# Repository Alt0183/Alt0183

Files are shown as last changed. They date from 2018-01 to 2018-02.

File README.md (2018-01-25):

Alt0183 est le caractère du point milieu, dont l'usage participe à l'égalité des représentations entre les femmes et les hommes dans l'écriture. C'est aussi une extension de clavier open source pour cliquer sans modération et susciter le débat !

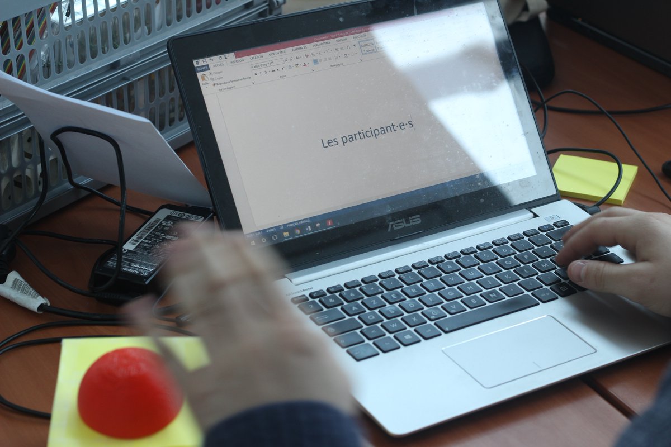
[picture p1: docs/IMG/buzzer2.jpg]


## Comment ça marche ?

- Fabriquez votre boîtier [en suivant les instructions ici](docs/INSTRUCTIONS)
- Connectez-le à votre ordinateur par USB, rien à installer
- Appuyez l'égalité dans le langage !

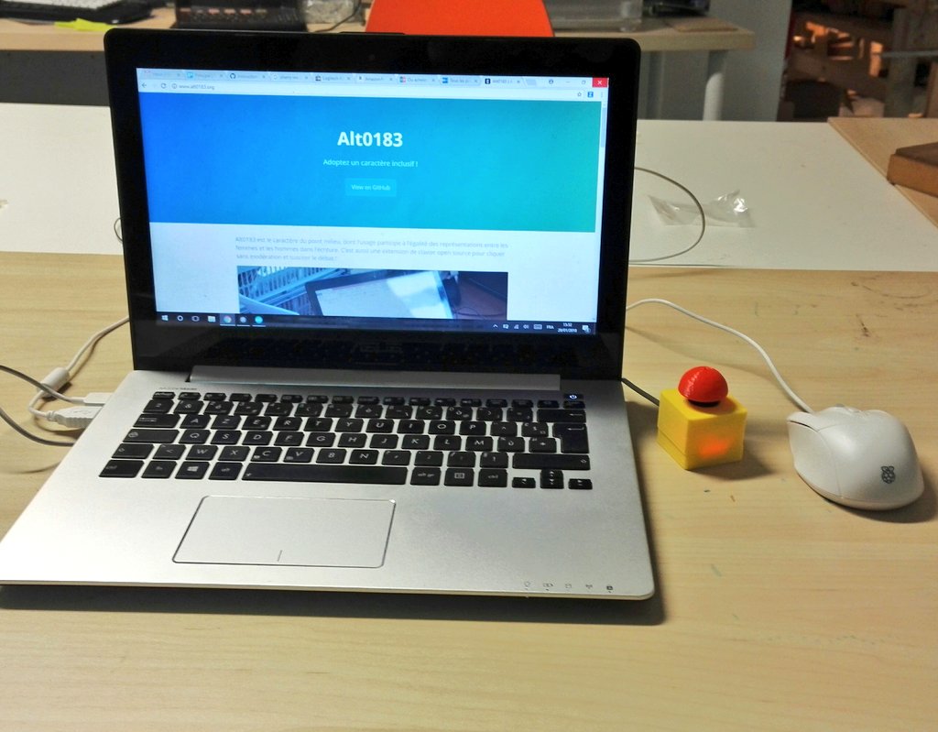
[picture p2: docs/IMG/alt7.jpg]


- Clic simple = "·"
- Double clic = "·es"

## Participez à un atelier pour fabriquer votre boitier Alt0183

Vous pensez ne pas savoir comment fabriquer un bouton Alt0183? Nous allons vous prouver le contraire! =)

Prochain atelier le 17 février à 14h au SimplonLab --> [INSCRIPTIONS](https://fabmanager.simplon.co/#!/events/31) 

## Ressources sur l'écriture inclusive

> « Le genre masculin ne sera plus regardé, même dans la grammaire, comme le genre le plus noble, attendu que tous les genres, tous les sexes et tous les êtres doivent être et sont également nobles. »  

*Requête des dames à l'Assemblée nationale, article 3 du Projet de décret adressé à la Législative, 1792.*

Voici une sélection de ressources pour alimenter vos discussions sur l'écriture inclusive et passer à l'action :

- [Le Guide pratique pour une communication publique sans stéréotype de sexe](http://www.haut-conseil-egalite.gouv.fr/stereotypes-et-roles-sociaux/zoom-sur/article/pour-une-communication-sans)

- [Le manuel d'écriture inclusive de l'agence Mots-Clés](http://www.ecriture-inclusive.fr/)

- [Épinglons-les : initiative militante pour l'emploi du langage inclusif en entreprise](https://epinglons-les.hotglue.me/?start.auto-20180114143251/)

- [Enrichissez votre vocabulaire en découvrant Égalexique, le lexique égalitaire](http://www.egalexique.com/)

- [Un programme collaboratif d'une semaine sur le thème du langage inclusif](http://semaineinclusive-hackecritureinclusive18.strikingly.com/)

## Suivre les avancées du projet

N'hésitez pas à nous laisser votre adresse mail pour être tenu·e informé·e des avancées du projet :

<script src="assets/js/jquery.min.js"></script>
<script type="text/javascript">var submitted=false;</script>
<script type="text/javascript">
$('#gform').on('submit', function(e) {
  $('#gform *').fadeOut(2000);
  $('#gform').prepend('Your submission has been processed...');
  });
</script>

<div style="text-align:center"><form name="gform" id="gform" enctype="text/plain" action="https://docs.google.com/forms/d/e/1FAIpQLSesBYaVCQM-NDpRlMn8QnpjHFccGZ0p6LW1I69tBJElzHB0rA/formResponse?" target="hidden_iframe" onsubmit="submitted=true;">
  Adresse mail:
  <input type="text" name="entry.119910746" id="entry.119910746">
  <!--Commentaire : <br>
  <input type="text" name="entry.383631987" id="entry.383631987"> -->
  <input type="submit" value="Envoyer">
</form>

<iframe name="hidden_iframe" id="hidden_iframe" style="display:none;" onload="if(submitted) {}"></iframe> <br>
</div>

Pour toute autre demande, n'hésitez pas à nous contacter par mail ou via les réseaux sociaux, nous ferons notre possible pour vous répondre le plus rapidement possible :

[Contact](mailto:contact.alt0183@gmail.com) | [Twitter](https://twitter.com/Alt0183_) | [Instagram](https://www.instagram.com/Alt0183)

# Contribuer

Vous souhaitez participer au projet? Organiser un atelier? Fabriquer, voire commercialiser, des boutons Alt0183?

Les différentes manières de s'impliquer dans le projet sont décrites sur [cette page](docs/contribuer).

---

Ce projet a été réalisé lors du Hackathon écriture inclusive 13/14 janvier 2018 par [Guillaume Marion](https://github.com/guillaumemarion) et est partagé sous licence GNU General Public License v3.0

Merci aux personnes ayant organisé ce hackathon, aux participant·es ainsi qu'aux sponsors!

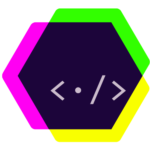
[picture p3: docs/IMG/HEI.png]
<div style="text-align:center"></div>

---

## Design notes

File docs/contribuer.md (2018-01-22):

# Contribuer au projet
Plusieurs moyens de contribuer au projet existent selon vos envies et vos compétences.

## Proposer des idées d'améliorations

Si vous avez une idée ou une proposition d'amélioration mais que vous ne savez pas comment la réaliser, il suffit d'aller dans l'onglet "issues" ci dessus et de la proposer. Cela permettra à celles et ceux qui savent coder/fabriquer d'essayer de les intégrer.

## Modifier le code, corriger un bug, proposer un boitier à imprimer en 3D, ajouter une version, etc...

Pour celles et ceux qui savent utiliser GitHub, vous pouvez directement proposer des CAO de boitier à imprimer en 3D, des améliorations de codes, des exemples de boitiers réalisés avec d'autres cartes Arduino, etc...
Pensez juste à ajouter une descriptions avant de commiter pour faciliter l'acceptation de vos modifications par les autres contributeur·rices

N'hésitez pas à aller faire un tour sur [la page "project"](https://github.com/guillaumemarion/Alt0183/projects/2) pour savoir quels sont les bugs ou les propositions d'améliorations à traiter et pour voir ce que font les autres.

## Organiser un atelier fabrication Alt0183

Si vous souhaitez organiser un atelier de fabrication d'Alt0183, n'hésitez pas! Pensez à nous prévenir pour que l'on diffuse l'invitation à votre atelier si vous le souhaitez

## Proposer des ressources à publier sur la page d'accueil

## Partagez vos photos

La meilleure reconnaissance que nous pouvons avoir de votre part est de savoir que vous utilisez Alt0183. N'hésitez donc pas à nous envoyer vos photos de vos versions de Alt0183 en situation par mail ou sur Instagram avec le hashtag #Alt0183!

## Envoyez nous un mail

Pour toute question, renseignement, problème ou autre, n'hésitez pas à nous [envoyer un mail](contact.alt0183@gmail.com)

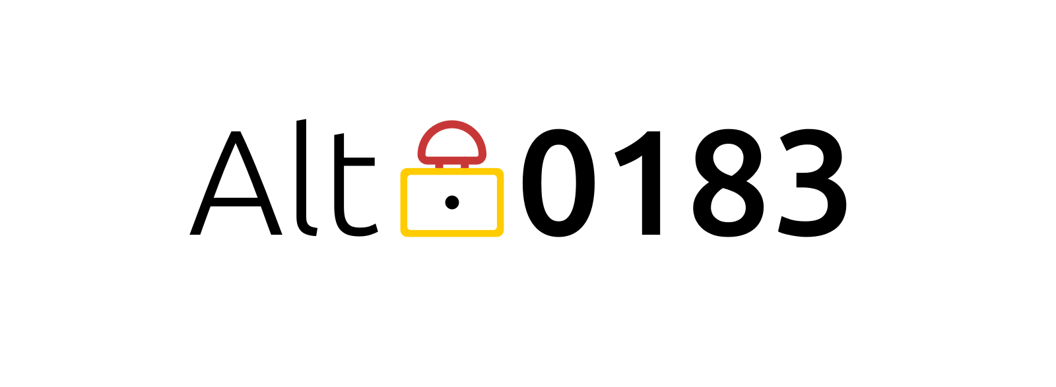
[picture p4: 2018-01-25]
docs/IMG/cover.png

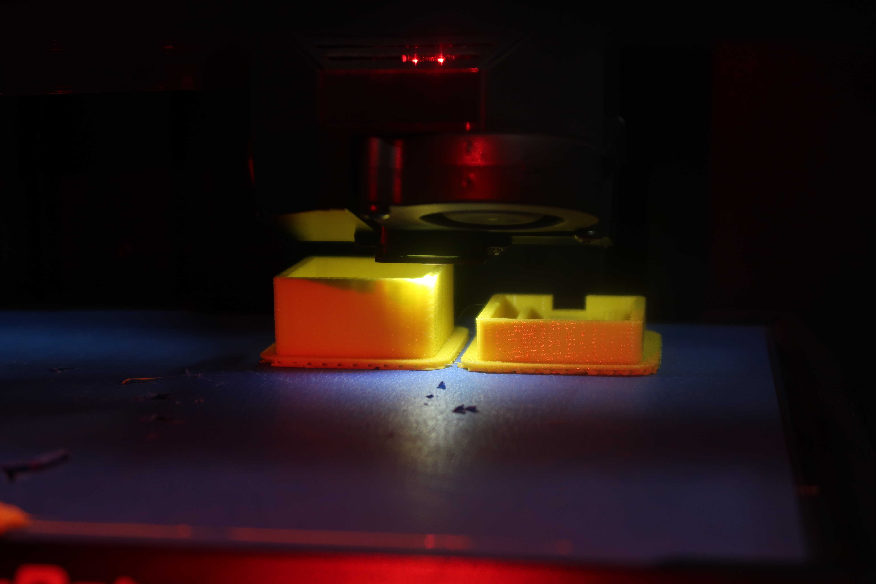
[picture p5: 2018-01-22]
docs/IMG/alt-1.jpg

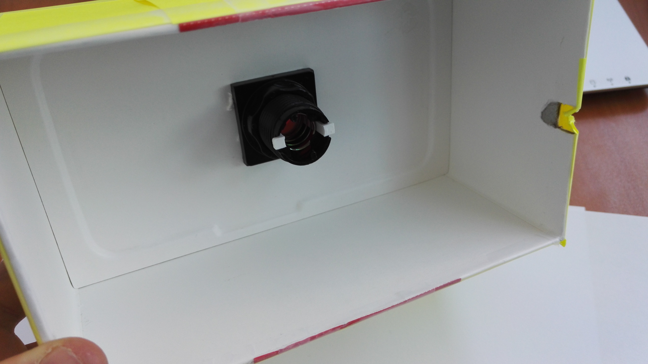
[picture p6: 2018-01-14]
docs/IMG/bouton.jpg

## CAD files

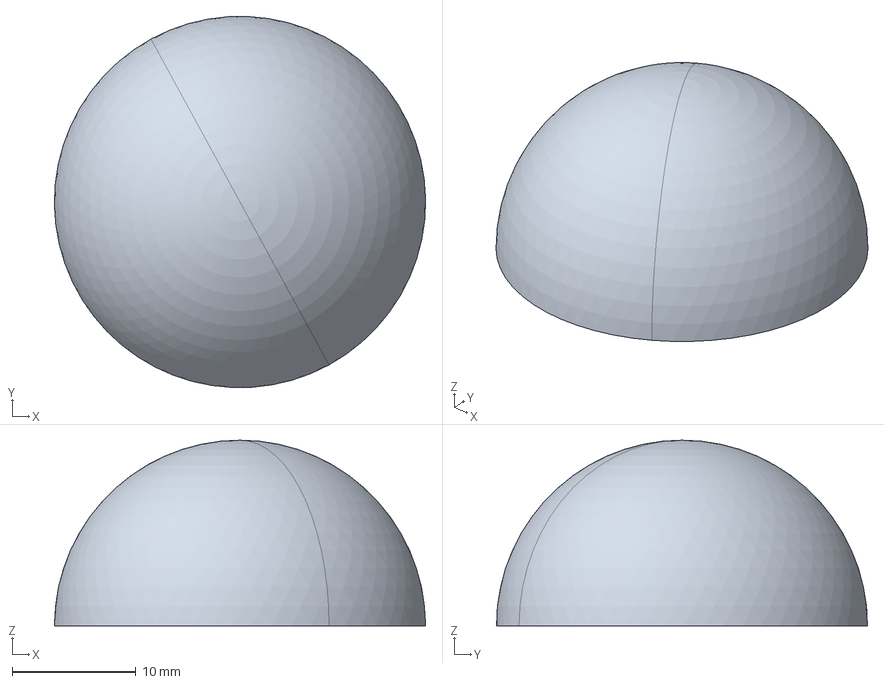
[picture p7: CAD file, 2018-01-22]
docs/CAO/STEP/buzzer.stp
30.0 x 30.0 x 15.0 mm

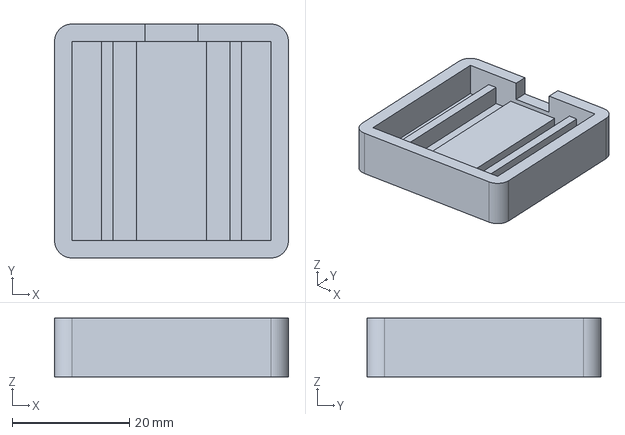
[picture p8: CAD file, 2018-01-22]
docs/CAO/STEP/Dessous.stp
40.0 x 40.0 x 10.0 mm

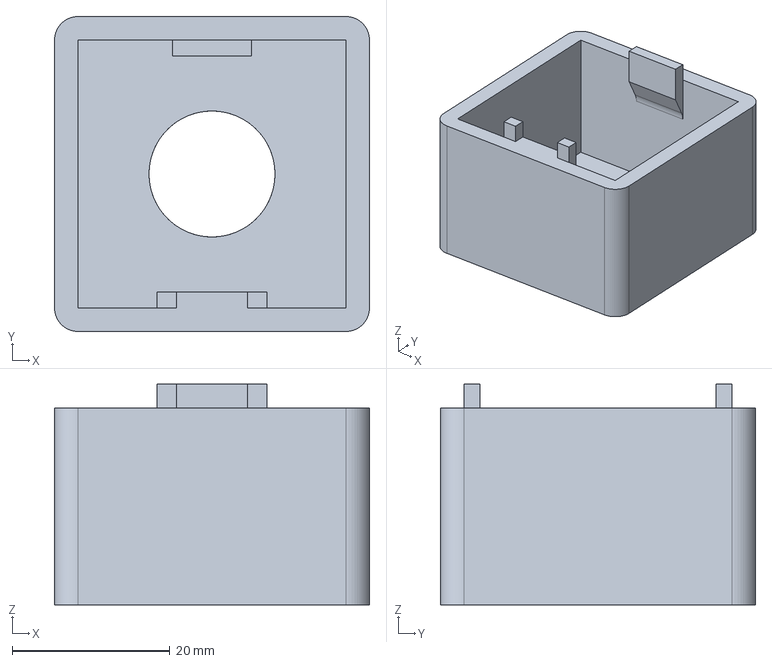
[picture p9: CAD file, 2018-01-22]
docs/CAO/STEP/dessus.stp
40.0 x 40.0 x 28.0 mm

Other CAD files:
docs/CAO/CATPart/Alt018.CATProduct
docs/CAO/CATPart/Dessous.CATPart
docs/CAO/CATPart/Leo.CATPart
docs/CAO/CATPart/buzzer.CATPart
docs/CAO/CATPart/dessus.CATPart
docs/CAO/STL/Dessous.stl
docs/CAO/STL/buzzer.stl
docs/CAO/STL/dessus.stl

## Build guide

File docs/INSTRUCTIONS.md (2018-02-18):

# Matériel nécessaire
Pour réaliser votre bouton Alt0183, vous aurez besoin des produits suivants :
* [une carte Arduino Pro Micro](https://www.amazon.fr/gp/product/B019SXN84E)
* [deux fils électriques](https://www.amazon.fr/Elegoo-Multicolore-M%C3%A2le-Femelle-M%C3%A2le-M%C3%A2le-Femelle-Femelle/dp/B01JD5WCG2)
* [un bouton poussoir](https://www.amazon.fr/gp/product/B01FDJLVFK)

> Les liens sont donnés à titre indicatifs. C'est ceux que nous avons utilisé pour le prototype donc nous savons que ce matériel est compatible. Cependant, ce projet est également réalisable avec une carte Arduino Leonardo et avec n'importe quel type de bouton poussoir. N'hésitez donc pas à adapter le matériel selon vos besoins ou ce que vous avez sous la main.

> Attention à ne pas confondre la carte Arduino Pro Micro avec une Arduino Nano ou Mini. Le microcontroleur est différent et ne permet pas de se faire passer pour un clavier. Par contre, la carte Leonardo
est compatible, cependant elle ne rentrera pas dans le boitier proposé ici. Si vous avez un doute lors du choix de la carte, l'important est de vérifier que le microcontrôleur soit un Atmega32u4.

Vous aurez également besoin des équipements suivants :
* fer à souder
* imprimante 3D

> Si vous ne disposez pas de ces outils, nous vous conseillons de prendre contact avec un fablab près de chez vous ou de passer par un service d'impression 3D à la demande comme [Sculpteo](www.sculpteo.com) ou [3DHubs](www.3dhubs.com).

# Impression 3D du boitier

Téléchargez les fichiers STL puis imprimez les en 3D :
* [Dessous](CAO/STL/Dessous.stl)
* [Dessus](CAO/STL/dessus.stl)
* [Buzzer](CAO/STL/buzzer.stl)

Dans notre cas, nous avons choisi d'imprimer le boitier en jaune et le buzzer en rouge mais libre à vous de choisir le filament de votre choix.

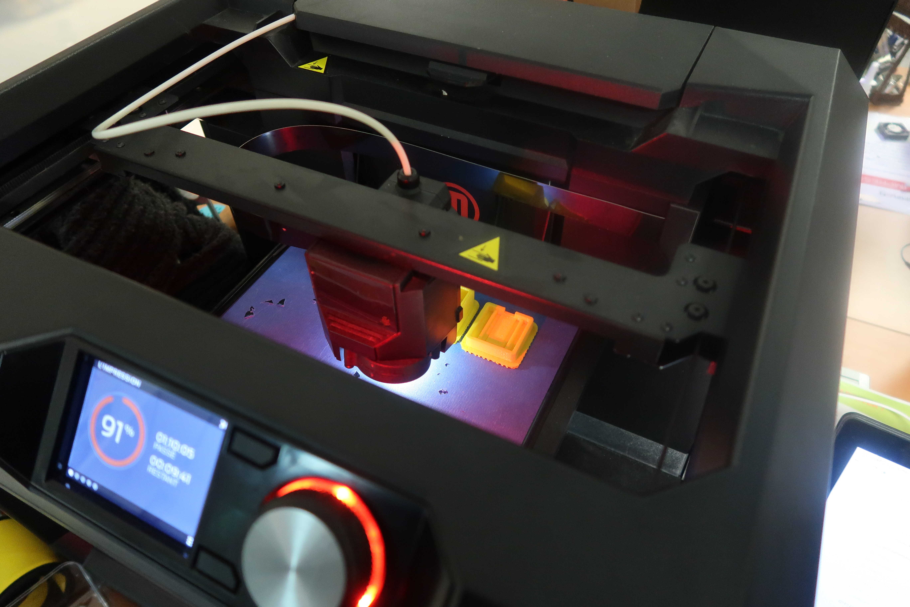
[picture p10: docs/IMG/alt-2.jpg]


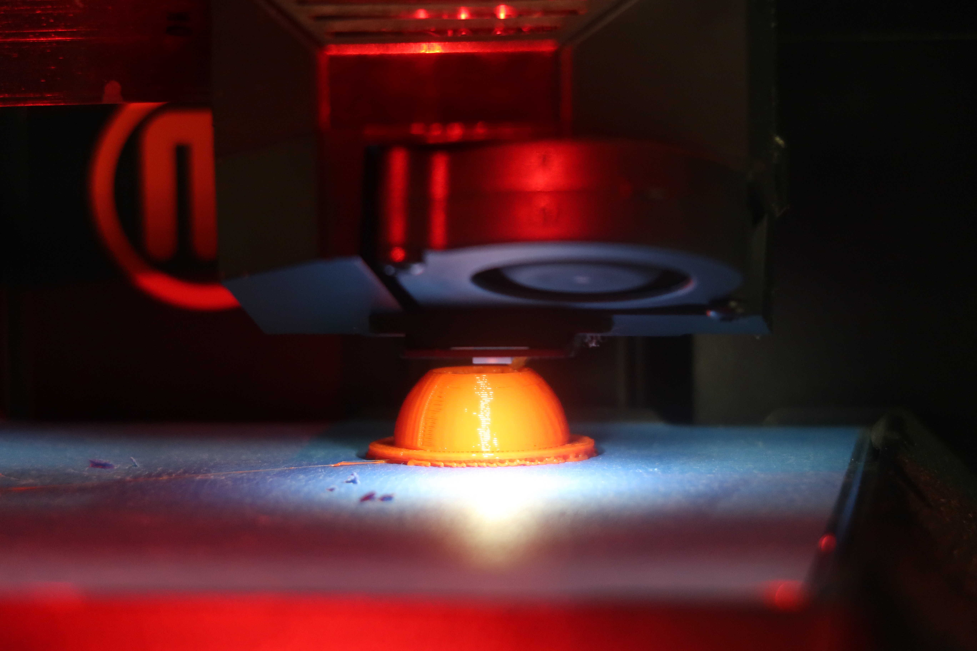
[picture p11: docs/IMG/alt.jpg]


# Fabrication et assemblage du boutton

## Cablage / Soudage

Soudez un fil sur chaque patte du bouton poussoir

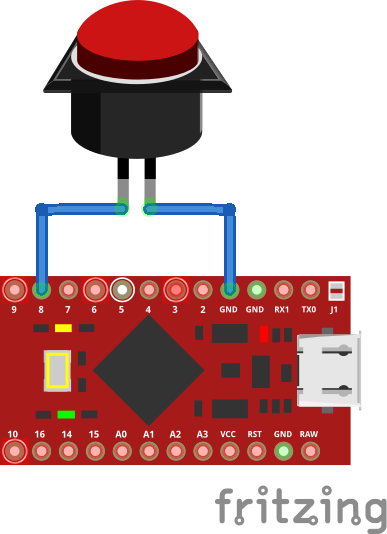
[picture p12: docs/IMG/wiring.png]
cablage


Dans certains cas il peut être également nécessaire de souder les broches sur la carte Arduino Pro Micro

## Montage du bouton dans le boitier

Visser le bouton dans le boitier :

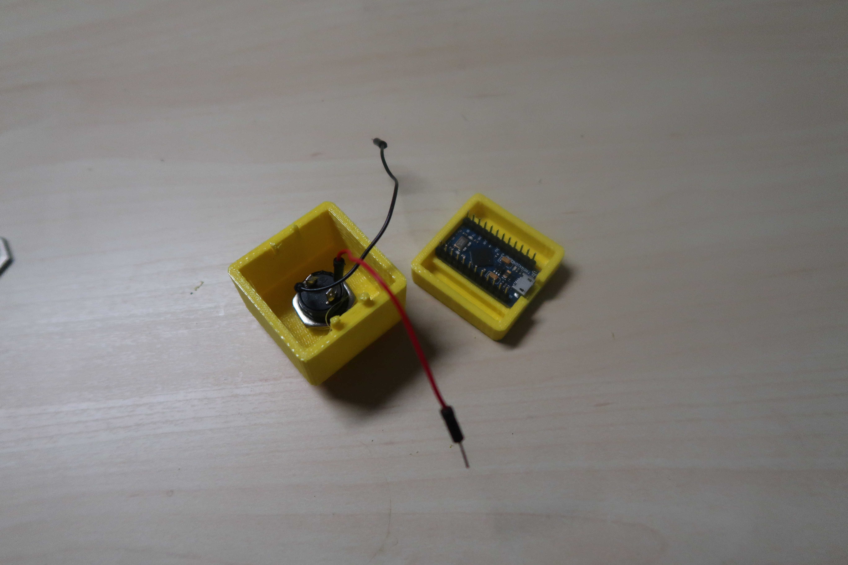
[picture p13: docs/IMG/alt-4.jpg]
assemblage


Brancher les deux fils du bouton sur la carte Arduino. Un des deux fils doit se brancher sur le port 8 et l'autre sur un port GND. Vous pouvez bien sur brancher autrement, mais il faudra alors apporter les modifications nécessaires dans le code Arduino.

Positionner l'arduino dans la boite et la refermer.

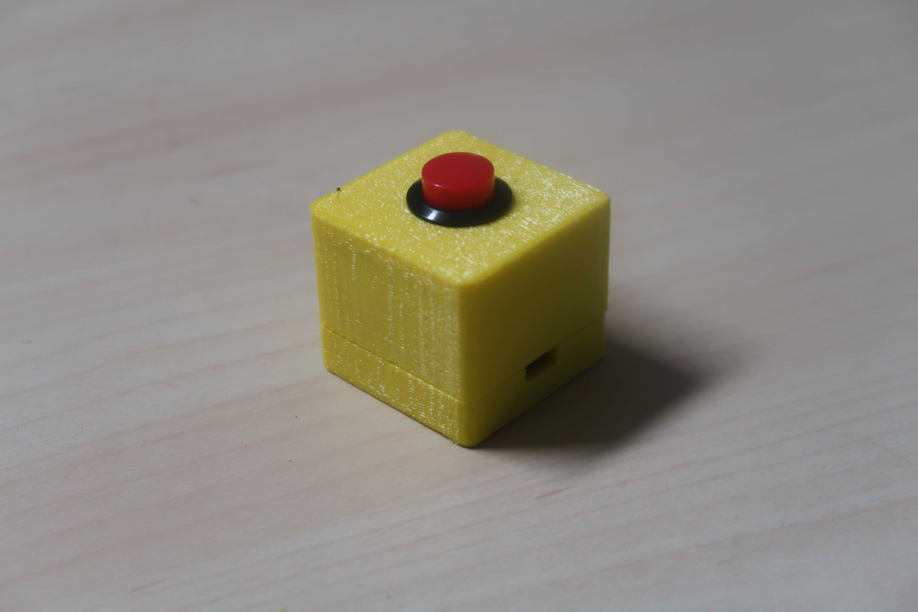
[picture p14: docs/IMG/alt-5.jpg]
Assemblage


## Collez le buzzer

Collez le buzzer sur le bouton poussoir avec de la colle néoprène ou de la super glue.

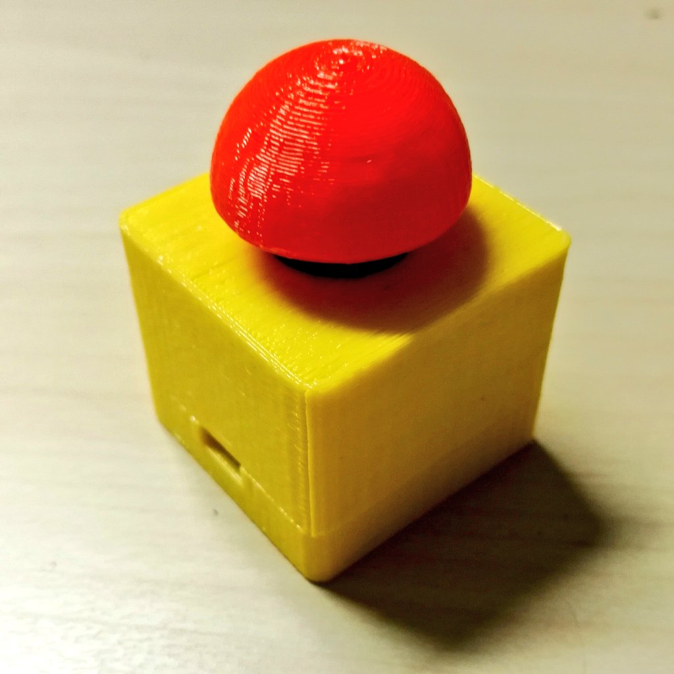
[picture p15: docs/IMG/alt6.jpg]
Assemblage final


# Programmation 
A cette étape, vous pouvez brancher l'arduino à votre ordinateur

## Installer le Logiciel arduino
Pour programmer votre carte Arduino vous aurez besoin d'installer le logiciel disponible sur la [page téléchargement du site Arduino](https://www.arduino.cc/en/Main/Software).

## Installation des librairies nécessaires à ce projet
Les librairies apportent des fonctions supplémentaires à Arduino. Dans ce projet, nous allons utiliser les librairies suivantes :
* Keyboard qui permet à la carte Arduino d'envoyer des signaux correspondant à des touches claviers
* oneButton qui permet de détecter un double clic

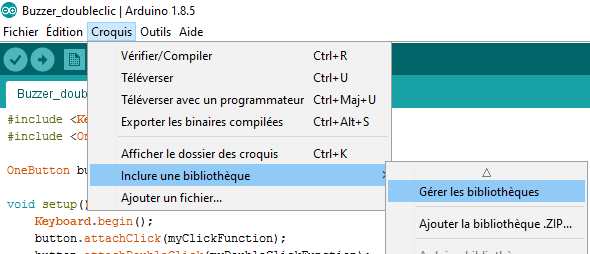
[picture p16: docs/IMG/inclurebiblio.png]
Installer des librairies


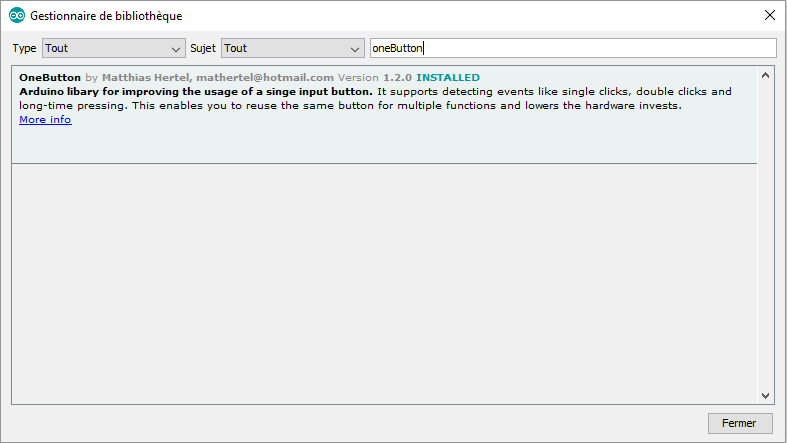
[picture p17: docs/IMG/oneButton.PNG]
Installer la librairie oneButton


Installer la librairie Keyboard

## Code

Dans la fenètre du logiciel Arduino, copiez le code disponible [sur ce lien](Alt0183_ProMicro.ino)

Votre fenêtre doit maintenant ressembler à cela :

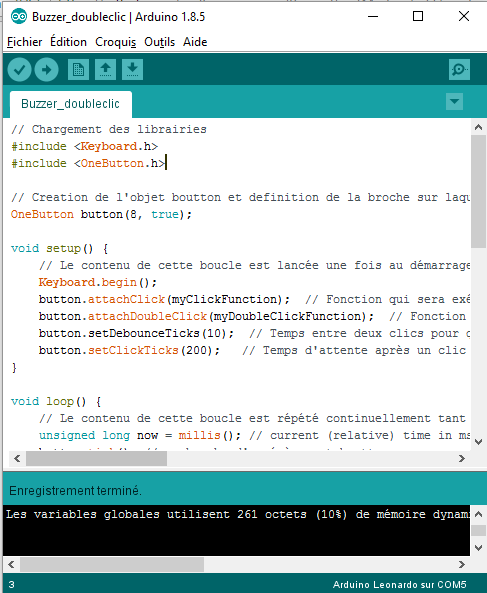
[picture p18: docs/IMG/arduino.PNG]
Fenetre Arduino après avoir collé le code


Settez votre système d'exploitation sur la ligne suivante :
```
const int OS = <votre OS>;
```
Pour Windows, utilisez `OS_PC`.
Pour Mac, utilisez `OS_MAC`.

Sauvegardez le fichier

## Téléverser le code sur la carte Arduino

La dernière étape consiste à envoyer ce code sur la carte Arduino. Pour celà :

* Sélectionnez le type de carte que vous utilisez dans le menu approprié :

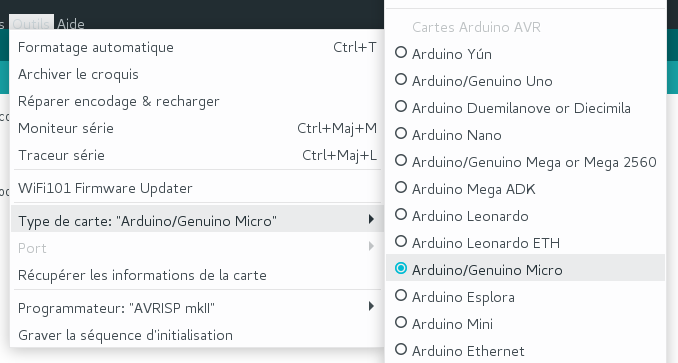
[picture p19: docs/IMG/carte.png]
Sélection de la carte


* Dans le menu "port" sélectionnez le seul disponible (le numéro derrière COM peut varier, ce n'est pas important)

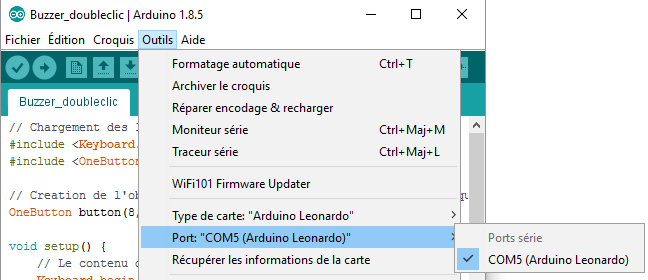
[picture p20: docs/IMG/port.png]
Sélection du port


* Cliquez sur le bouton téléverser en forme de flèche pour envoyer le script sur l'Arduino :

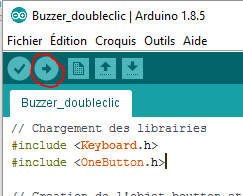
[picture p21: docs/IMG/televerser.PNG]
televerser


Si la partie noire en bas de la fenètre ne renvoie que du texte écrit en blanc et pas d'erreur (écrites en orange), le script est bien chargé sur l'Arduino :

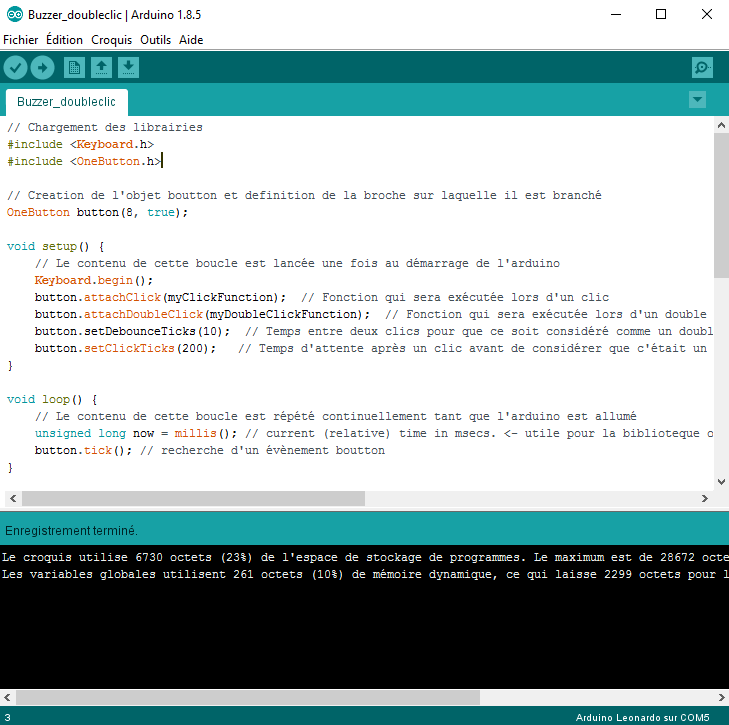
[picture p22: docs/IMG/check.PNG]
check


# Partagez

Voilà, vous avez réalisé un Alt0183! Pensez à nous envoyer une photo en situation [par mail](mailto:contact.alt0183@gmail.com) ou sur Instagram avec le hashtag #Alt0183!

# En cas de problème

Allez dans l'onglet "Issues" de ce site et décrivez votre problème. Nous ferons notre possible pour vous répondre au plus vite.

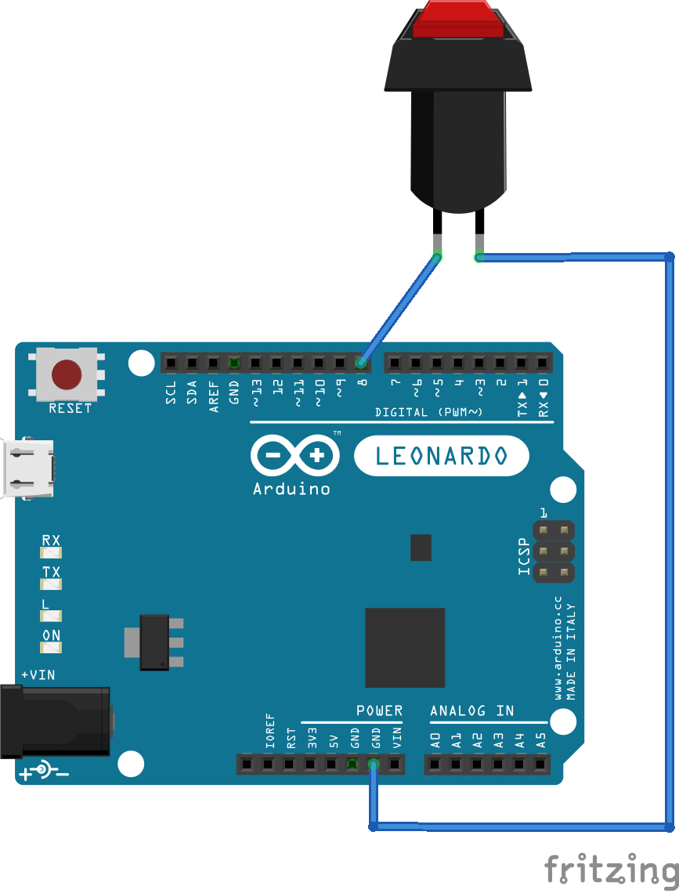
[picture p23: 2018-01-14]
docs/IMG/wiring_leo.png

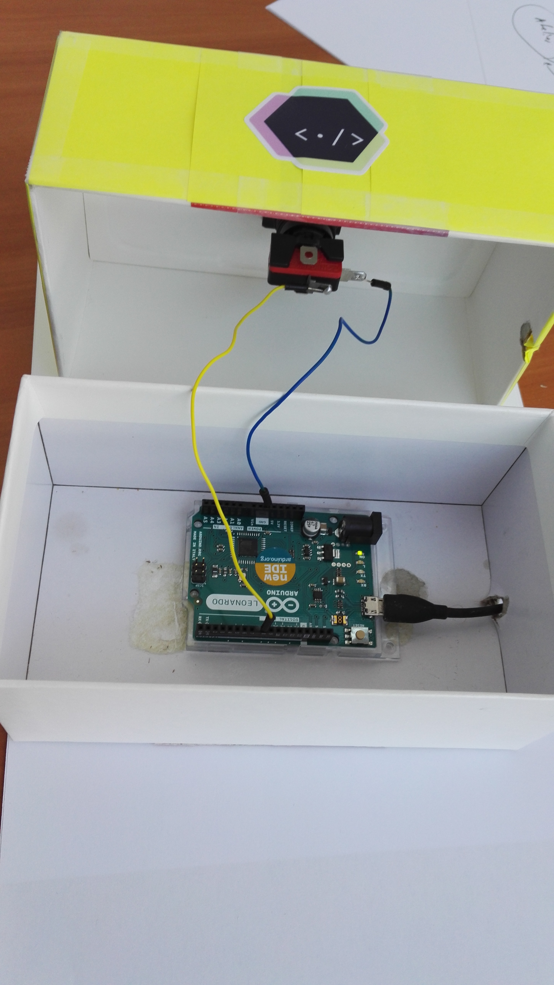
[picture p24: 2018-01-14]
docs/IMG/montage.jpg

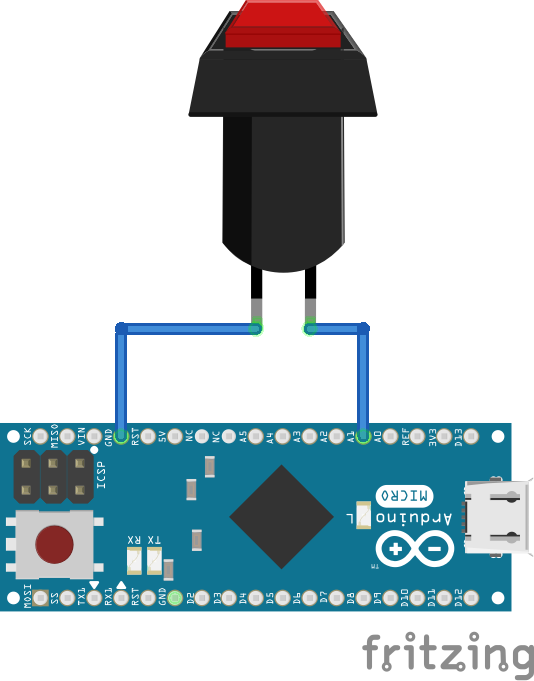
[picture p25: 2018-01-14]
docs/IMG/wiring_leo_pro.png

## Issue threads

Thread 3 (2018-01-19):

Faire une version compatible mac

guillaumemarion, 2018-01-19:

guillaumemarion, 2018-01-20:
décider si :
- un seul script avec partie dépendante de la plateforme à décommenter
- un script par plateforme et les utilisateur·ices téléchargent la version qui leur va

Closed 2018-02-18.

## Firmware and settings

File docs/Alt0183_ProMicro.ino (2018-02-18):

// Chargement des librairies
#include <Keyboard.h>
#include <OneButton.h>

const int OS_PC = 0;
const int OS_MAC = 1;

// Set OS
const int OS = OS_MAC;

// Creation de l'objet boutton et definition de la broche sur laquelle il est branché
OneButton button(8, true);

void setup() {
    // Le contenu de cette boucle est lancée une fois au démarrage de l'arduino
    Keyboard.begin(); 
    button.attachClick(myClickFunction);  // Fonction qui sera exécutée lors d'un clic
    button.attachDoubleClick(myDoubleClickFunction);  // Fonction qui sera exécutée lors d'un double clic
    button.setDebounceTicks(10);  // Temps entre deux clics pour que ce soit considéré comme un double clic (en ms)
    button.setClickTicks(200);   // Temps d'attente après un clic avant de considérer que c'était un simple clic(en ms) attention, mettre un temps trop court peut empécher de réaliser un double clic
}

void loop() {
    // Le contenu de cette boucle est répété continuellement tant que l'arduino est allumé
    unsigned long now = millis(); // current (relative) time in msecs. <- utile pour la biblioteque oneButton
    button.tick(); // recherche d'un évènement boutton
}

void ptMed() {
        if (OS == OS_PC) {
          // Envoie Alt+0183 pour Windows
          Keyboard.press(KEY_LEFT_ALT);
          Keyboard.press(234);
          delay(10);
          Keyboard.release(234);
          Keyboard.press(225);
          delay(10);
          Keyboard.release(225);
          Keyboard.press(232);
          delay(10);
          Keyboard.release(232);
          Keyboard.press(227);
          delay(10);
          Keyboard.release(227);
          Keyboard.releaseAll();
        }

        if (OS == OS_MAC) {
          // Envoie Option+Maj+F pour Mac
          Keyboard.press(KEY_LEFT_ALT);
          Keyboard.press(KEY_LEFT_SHIFT);
          Keyboard.press('F');
          delay(10);
          Keyboard.releaseAll();
        }
}

void myClickFunction() {
        // Cette fonction est appelée lors d'un clic simple
        ptMed();   // point médian
}

void myDoubleClickFunction() {
        // Cette fonction est appelée lors d'un double clic 
        ptMed();
        delay(10);
        Keyboard.print("es");
}

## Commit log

2018-01-19 Upload des fichiers CAO du buzzer
    [Alt018.CATProduct, Dessous.CATPart, Dessous.stl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]
2018-01-19 Création du script arduino pour la version leonardo
2018-01-20 Réorganisation des dossiers
    [Alt018.CATProduct, Dessous.CATPart, Dessous.stl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]
2018-01-22 Réorganisation et rédaction tuto
    [Alt018.CATProduct, Dessous.CATPart, Dessous.stl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]
2018-01-22 Instructions -> Docs
    [Alt018.CATProduct, Dessous.CATPart, Dessous.stl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]
2018-01-22 Grosse réorga et simplification du git
    [Alt018.CATProduct, Dessous.CATPart, Dessous.stl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]
2018-01-22 correction des liens vers les images dans readme
2018-01-22 Docs -> docs
    [Alt018.CATProduct, Dessous.CATPart, Dessous.stl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]
2018-01-22 corrction de llien vers les img
2018-01-23 modification de INSTRUCTIONS
2018-01-23 Modification de la page comment contribuer
